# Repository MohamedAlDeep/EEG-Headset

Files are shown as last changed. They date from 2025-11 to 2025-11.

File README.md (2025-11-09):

# ADS1299 EEG Headset 🧠
This is a DIY / custom *electroencephalogram* reading device which is connected eeg electrodes that can connect to brain at designated areas.

It reads brain wave signals and digitizes them into the computer which is called brain-computer interface.

### Why am i doing this
I have a larger project and i want to join the competition with my pcb.

### The schematic 
This is the board schematic.
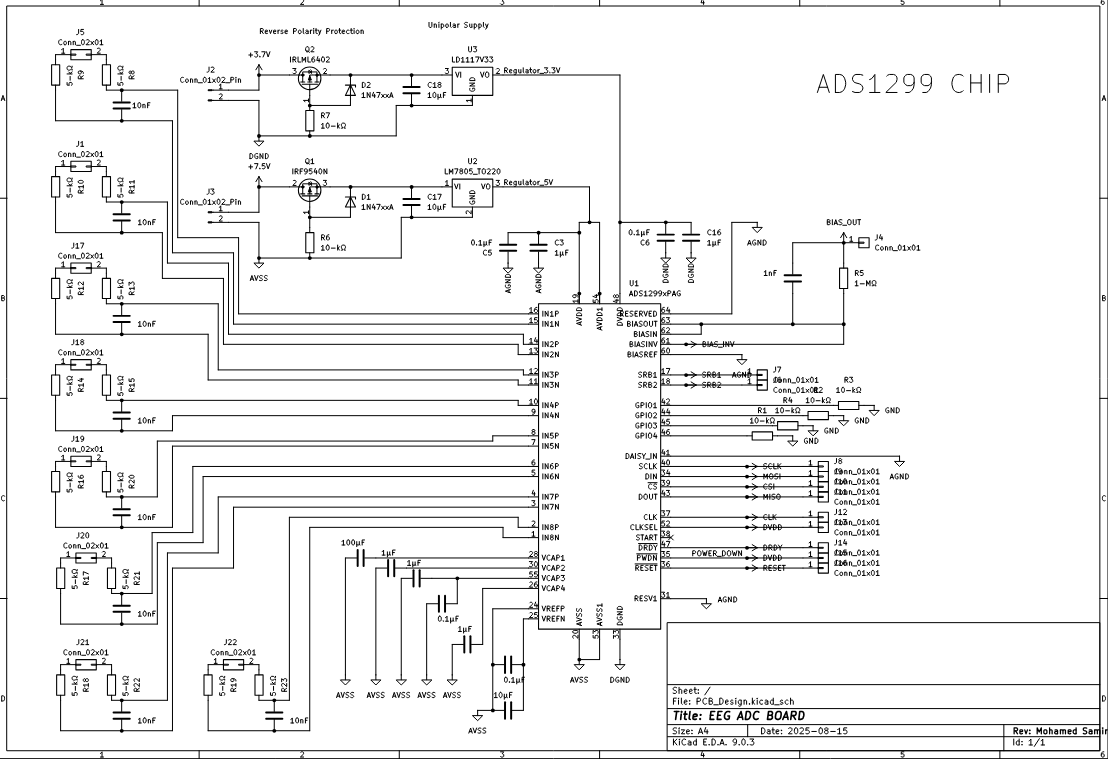
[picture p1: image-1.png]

### PCB
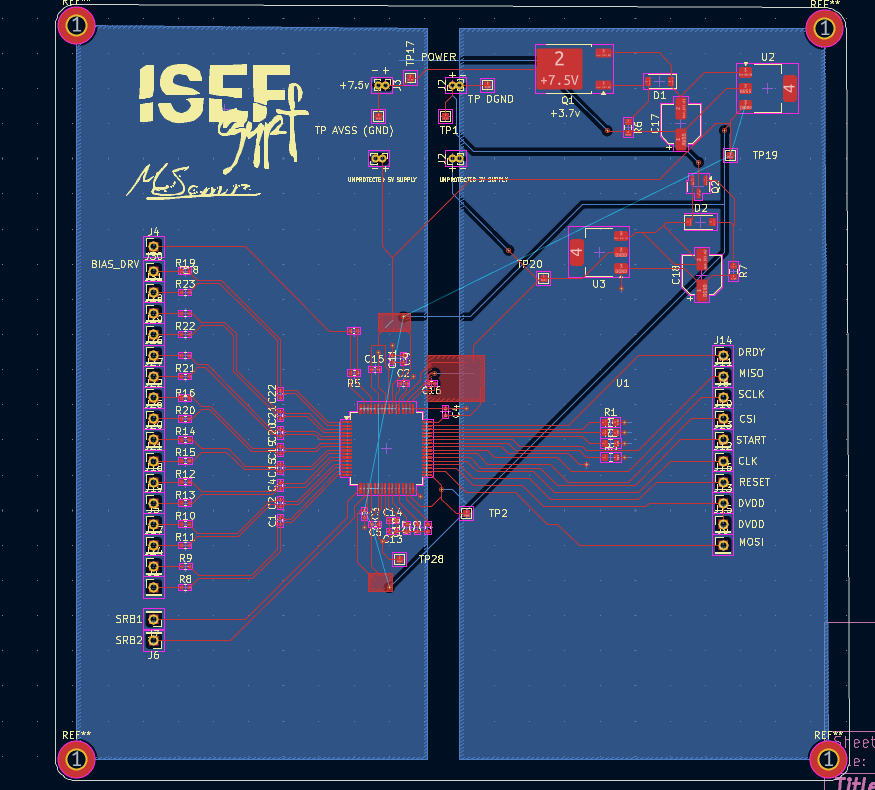
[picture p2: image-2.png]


### Mounting Part
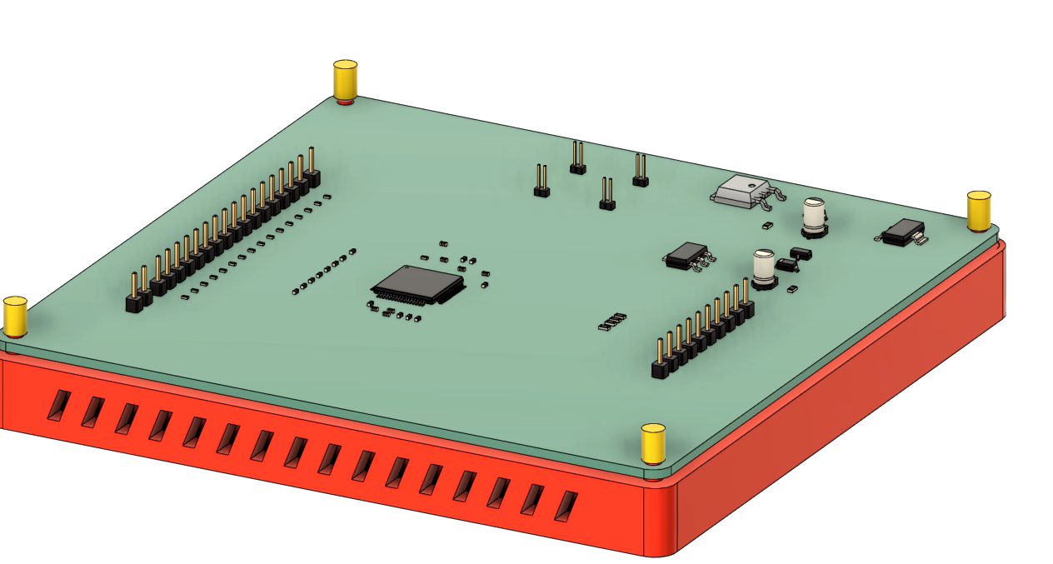
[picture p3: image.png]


### BOM 

| Item | Recommended_LCSC_PN | Package | JLCPCB_Type | URL | Unit Price | Amount | Total |
|:---|:---|:---|:---|:---|:---|:---|:---|
| EEG Electrodes | | | | https://ar.aliexpress.com/item/1005003431845612.html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 | 26.75 | 2.0 | 53.5 |
| 100nF (Original 6.3V) | C1525 | 402 | Basic | https://jlcpcb.com/partdetail/1877-CL05B104KO5NNNC/C1525 | $0.01 | 4.0 | 4 |
| 10nF | C1524 | 402 | Basic | https://jlcpcb.com/partdetail/1876-0402B103K500NT/C1524 | $0.01 | 9.0 | 0.09 |
| 1μF | C15684 | 402 | Basic | https://jlcpcb.com/partdetail/MurataElectronics-GRM155R60J105KE19D/C15684 | $0.01 | 7.0 | 0.07 |
| 10μF | C15849 | 402 | Basic | | $0.01 | 1.0 | 0.01 |
| 10μF (Electrolytic) | C86604 | CP_Elec_5x5.4  | Extended | https://jlcpcb.com/partdetail/HonorElec-RVT1E100M0505/C86604 | $0.03 | 2.0 | 0.06 |
| 10kΩ | C25804 | 603 | Basic | https://jlcpcb.com/partdetail/26547-0603WAF1002T5E/C25804 | 0.01 | 6.0 | 0.06 |
| 1MΩ | C26083 | 402 | Extended | https://jlcpcb.com/partdetail/26826-0402WGF1004TCE/C26083 | 0.01 | 1.0 | 0.01 |
| 5kΩ | C477765 | 402 | Extended | https://jlcpcb.com/partdetail/YAGEO-RC0402FR075KL/C477765 | $0.01 | 16.0 | 0.16 |
| 3.3V LDO | C5018 (AMS1117-3.3) | SOT-223 | Basic | https://jlcpcb.com/partdetail/Advanced_MonolithicSystems-AMS1117_33/C6186 | 0.16 | 1.0 | 0.16 |
| 5V LDO | C5019 (AMS1117-5.0) | SOT-223 | Basic | https://jlcpcb.com/partdetail/Advanced_MonolithicSystems-AMS1117_50/C6187 | 0.19 | 1.0 | 0.19 |
| P-MOSFET (SOT-23) | C10487 | SOT-23 | Basic | https://jlcpcb.com/partdetail/VishayIntertech-SI2301CDS_T1GE3/C10487 | 0.05 | 1.0 | 0.05 |
| FQD4P50 (P-MOSFET) | C17265 | SMD:SOT-223 | Extended | https://jlcpcb.com/partdetail/onsemi-NTF2955T1G/C17265 | 0.47 | 1.0 | 0.47 |
| Conn 1×01 Pin | C2938454 | SMT Pin Header | Basic | https://jlcpcb.com/partdetail/3294834-KH_2PH180_1X10P_L87/C2938454 | 0.05 | 2.0 | 0.1 |
| ADS1299IPAGR | C476817 | TQFP-64(10x10) | Economic and Standard | https://jlcpcb.com/partdetail/TexasInstruments-ADS1299IPAGR/C476817 | 30.66 | 1.0 | 30.66 |
| Total | | | | | | | 89.59 |

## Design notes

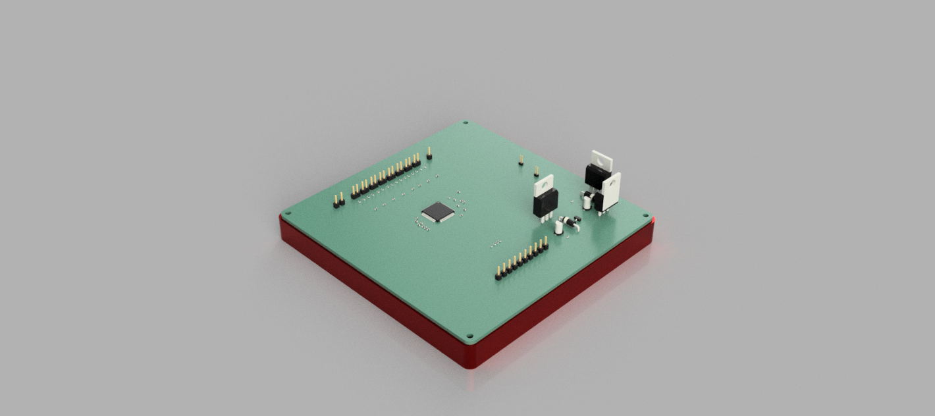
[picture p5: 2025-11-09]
Media/PCB_Holder v2.png

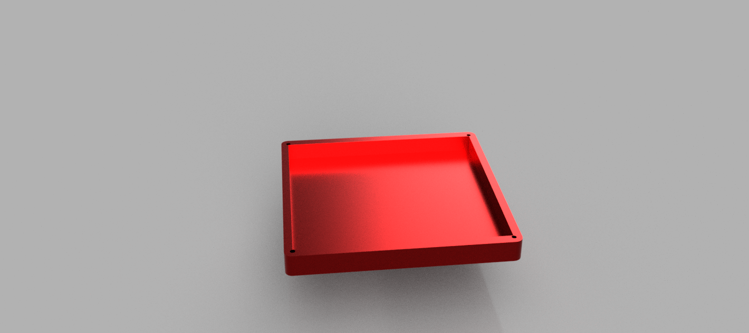
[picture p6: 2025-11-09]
Media/PCB_Holder v2 2.png

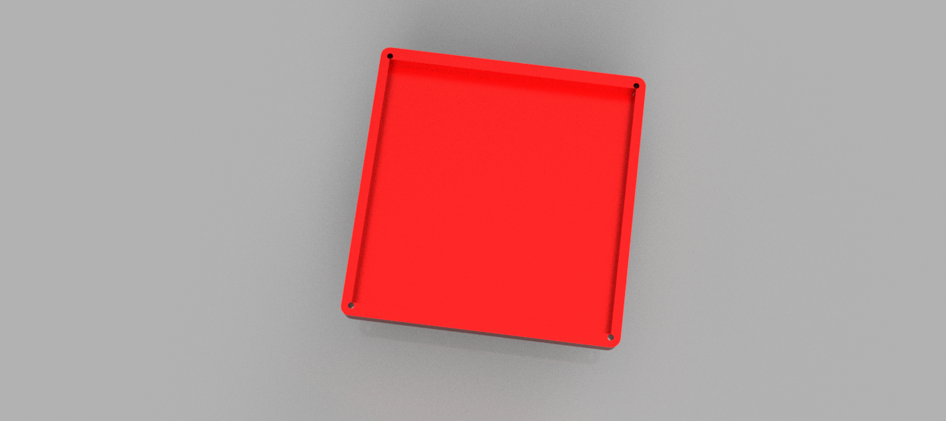
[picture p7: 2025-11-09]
Media/PCB_Holder v2 3.png

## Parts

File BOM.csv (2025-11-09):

Item | Recommended_LCSC_PN | Package | JLCPCB_Type | URL | Unit Price | Amount | Total
EEG Electrodes |  |  |  | https://ar.aliexpress.com/item/1005003431845612.html?curPageLogUid=TJmvYjdGyCeK | 26.75 | 2 | 53.5
100nF (Original 6.3V) | C1525 | 402 | Basic | https://jlcpcb.com/partdetail/1877-CL05B104KO5NNNC/C1525 | $0.01 | 4 | 4
10nF | C1524 | 402 | Basic | https://jlcpcb.com/partdetail/1876-0402B103K500NT/C1524 | $0.01 | 9 | 0.09
1μF | C15684 | 402 | Basic | https://jlcpcb.com/partdetail/MurataElectronics-GRM155R60J105KE19D/C15684 | $0.01 | 7 | 0.07
10μF | C15849 | 402 | Basic |  | $0.01 | 1 | 0.01
10μF (Electrolytic) | C86604 | CP_Elec_5x5.4 | Extended | https://jlcpcb.com/partdetail/HonorElec-RVT1E100M0505/C86604 | $0.03 | 2 | 0.06
10kΩ | C25804 | 603 | Basic | https://jlcpcb.com/partdetail/26547-0603WAF1002T5E/C25804 | 0.01 | 6 | 0.06
1MΩ | C26083 | 402 | Extended | https://jlcpcb.com/partdetail/26826-0402WGF1004TCE/C26083 | 0.01 | 1 | 0.01
5kΩ | C477765 | 402 | Extended | https://jlcpcb.com/partdetail/YAGEO-RC0402FR075KL/C477765 | $0.01 | 16 | 0.16
3.3V LDO | C5018 (AMS1117-3.3) | SOT-223 | Basic | https://jlcpcb.com/partdetail/Advanced_MonolithicSystems-AMS1117_33/C6186 | 0.16 | 1 | 0.16
5V LDO | C5019 (AMS1117-5.0) | SOT-223 | Basic | https://jlcpcb.com/partdetail/Advanced_MonolithicSystems-AMS1117_50/C6187 | 0.19 | 1 | 0.19
P-MOSFET (SOT-23) | C10487 | SOT-23 | Basic | https://jlcpcb.com/partdetail/VishayIntertech-SI2301CDS_T1GE3/C10487 | 0.05 | 1 | 0.05
FQD4P50 (P-MOSFET) | C17265 | SMD:SOT-223 | Extended | https://jlcpcb.com/partdetail/onsemi-NTF2955T1G/C17265 | 0.47 | 1 | 0.47
Conn 1×01 Pin | C2938454 | SMT Pin Header | Basic | https://jlcpcb.com/partdetail/3294834-KH_2PH180_1X10P_L87/C2938454 | 0.05 | 2 | 0.1
ADS1299IPAGR | C476817 | TQFP-64(10x10) | Economic and Standard | https://jlcpcb.com/partdetail/TexasInstruments-ADS1299IPAGR/C476817 | 30.66 | 1 | 30.66
Total |  |  |  |  |  |  | 89.59

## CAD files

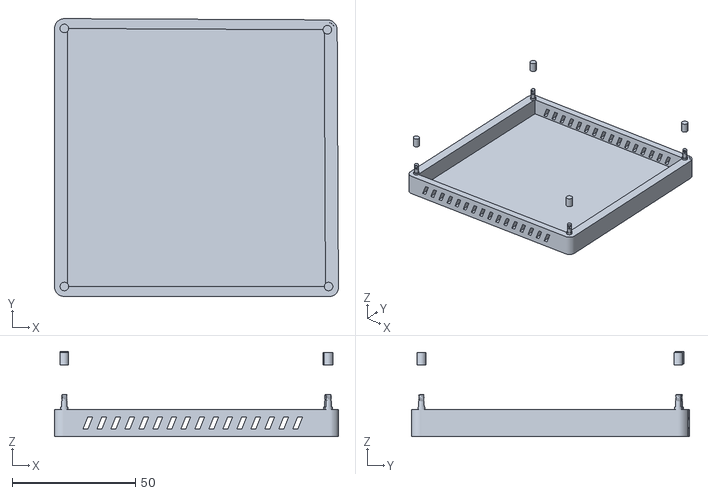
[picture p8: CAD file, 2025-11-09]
CAD/PCB_Holder_.stl
115.0 x 112.5 x 34.5

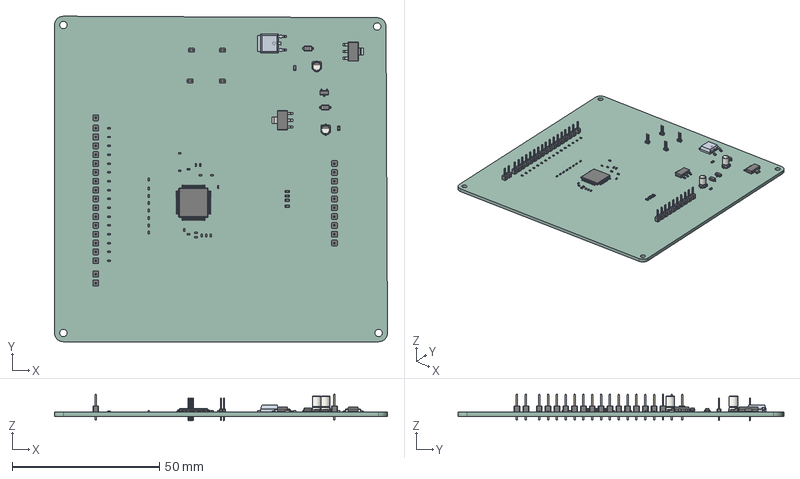
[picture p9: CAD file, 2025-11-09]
CAD/PCB_Design.step
113.0 x 110.5 x 9.00 mm
PinHeader_1x01_P2.00mm_Vertical x 29
R_0402_1005Metric x 17
C_0402_1005Metric x 22
SOT-23
R_0603_1608Metric x 6
D_SOD-123 x 2
PinHeader_1x02_P1.00mm_Vertical x 4
SOT-223 x 2
CP_Elec_3x5.4 x 2
TQFP-64_10x10mm_P0.5mm
PCB_Design 1.82.1
PCB_Design_PCB

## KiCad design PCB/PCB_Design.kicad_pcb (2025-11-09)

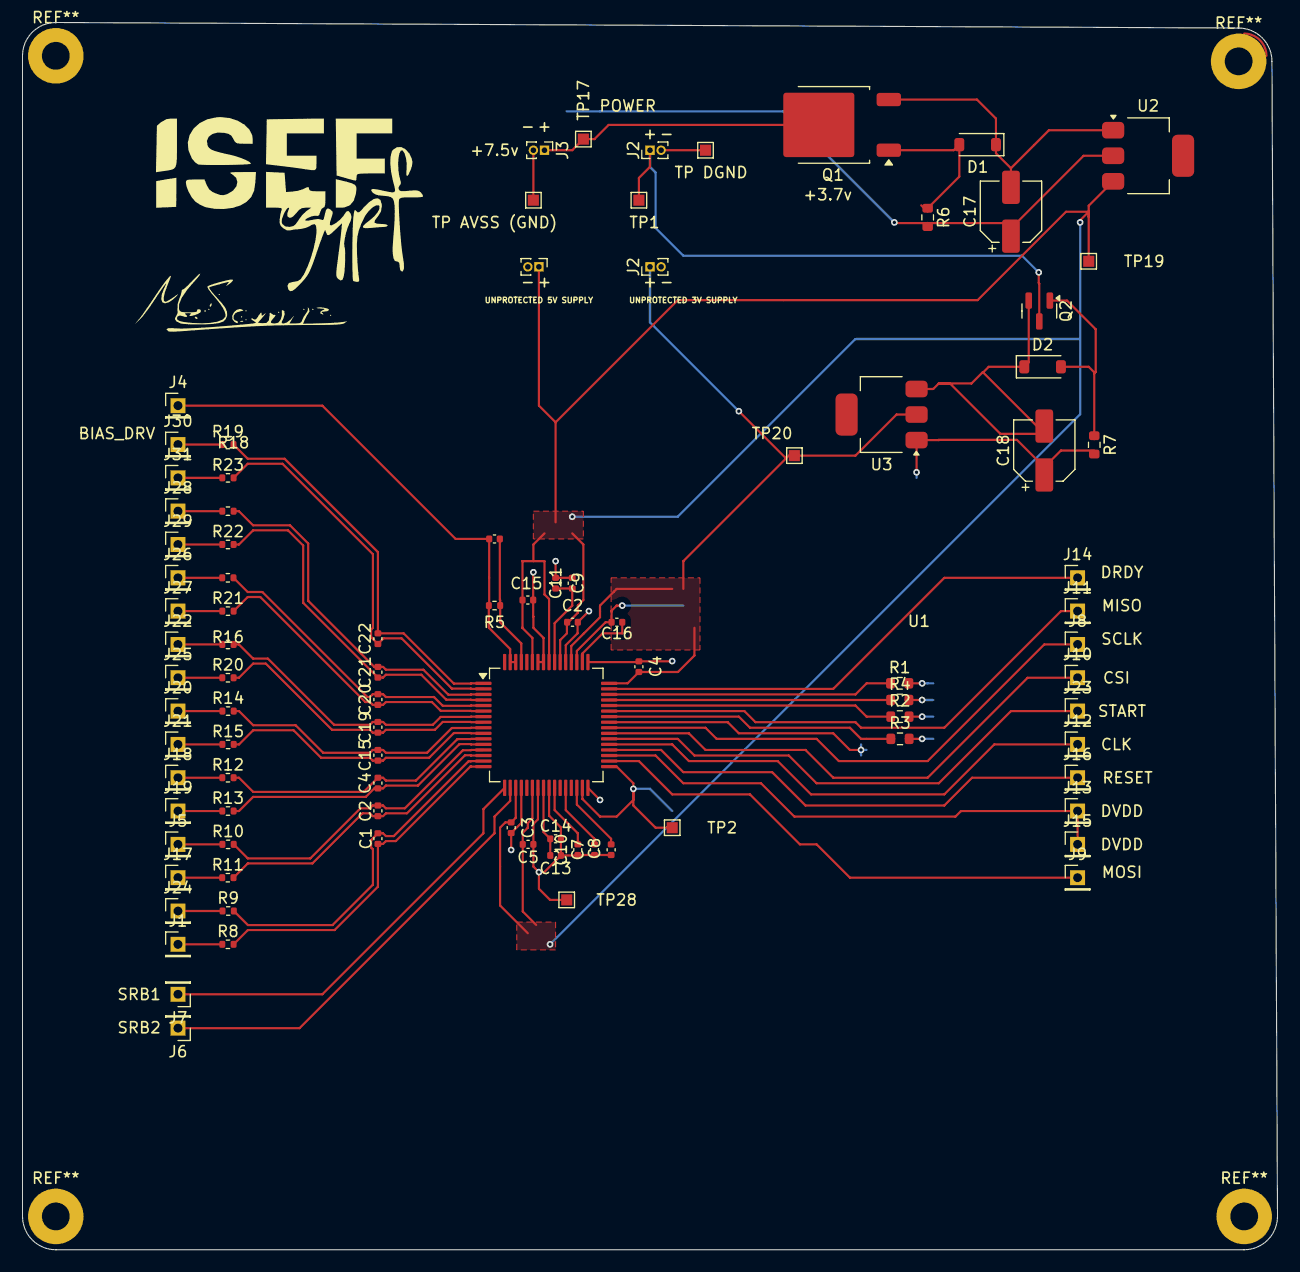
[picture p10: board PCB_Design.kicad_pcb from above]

Board: 2 copper layers, 113.0 x 110.5 mm, 95 parts (0 on the bottom side), 52 nets.

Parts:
C1, C2, C4, C12, C15#2, C19, C20, C21, C22: 10nF; C_0402_1005Metric
C2#2, C3, C8, C9, C10, C15, C16: 1μF; C_0402_1005Metric
C4#2: 100nF; C_0402_1005Metric
C5, C11, C13: 0.1μF; C_0402_1005Metric
C7: 100μF; C_0402_1005Metric
C14: 10μF; C_0402_1005Metric
C17, C18: 10μF; CP_Elec_5x5.4
D1: BZT52C5V1-W8 5.1V Zener 500mW; D_SOD-123
D2: 1N47xxA; D_SOD-123
J1, J4, J5, J6, J7, J8, J9, J10, J11, J12, J13, J14, J15, J16, J17, J18, J19, J20, J21, J22, J23, J24, J25, J26, J27, J28, J29, J30, J31: Conn_01x01; PinHeader_1x01_P2.00mm_Vertical
J2, J2#2, J3: Conn_01x02_Pin; PinHeader_1x02_P1.00mm_Vertical
Q1: FQD4P50 (P-MOSFET); TO-252-2
Q2: IRLML6402; SOT-23
R1, R2, R3, R4, R6, R7: 10-kΩ; R_0603_1608Metric
R5: 1-MΩ; R_0402_1005Metric
R8, R9, R10, R11, R12, R13, R14, R15, R16, R17, R18, R19, R20, R21, R22, R23: 5-kΩ; R_0402_1005Metric
TP1, TP2, TP17, TP19, TP20, TP28: TestPoint; TestPoint_Pad_1.0x1.0mm
TP AVSS (GND): TestPoint; TestPoint_Pad_1.0x1.0mm
TP DGND: TestPoint; TestPoint_Pad_1.0x1.0mm
U1: ADS1299xPAG; TQFP-64_10x10mm_P0.5mm
U2: LM7805_TO220; SOT-223
U3: AMS1117-3.3; SOT-223
UNPROTECTED 5V SUPPLY: Conn_01x02_Pin; PinHeader_1x02_P1.00mm_Vertical

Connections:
+3.7V: J2#2.1, Q2.3 (D), TP1.1
+7.5V: J3.1, Q1.2 (D), TP17.1
/AVDD: C3.1, C5.2, TP19.1, U2.3 (VO)
/IN+: C1.2, C2.1, C4.1, C15#2.1, C19.1, C20.1, C21.1, C22.1, R8.2, R11.2, R13.2, R15.2, R20.2, R21.2, R22.2, R23.2, U1.2 (IN8P), U1.4 (IN7P), U1.6 (IN6P), U1.8 (IN5P), U1.10 (IN4P), U1.12 (IN3P), U1.14 (IN2P), U1.16 (IN1P)
/IN-: C1.1, C2.2, C4.2, C15#2.2, C19.2, C20.2, C21.2, C22.2, R9.2, R10.2, R12.2, R14.2, R16.2, R17.2, R18.2, R19.2, U1.1 (IN8N), U1.3 (IN7N), U1.5 (IN6N), U1.7 (IN5N), U1.9 (IN4N), U1.11 (IN3N), U1.13 (IN2N), U1.15 (IN1N)
AGND: U1.60 (BIASREF), U1.64 (RESERVED)
AVDD: C2#2.1, C15.1, UNPROTECTED 5V SUPPLY.1
AVSS: C2#2.2, C3.2, C5.1, C7.1, C8.1, C9.1, C10.1, C11.2, C13.1, C14.2, C15.2, C17.1, J3.2, R6.2, TP28.1, TP AVSS (GND).1, U1.20 (AVSS), U1.23 (AVSS), U1.25 (VREFN), U1.32 (AVSS), U1.53 (AVSS1), U1.57 (AVSS), U1.58 (AVSS), U2.2 (GND), UNPROTECTED 5V SUPPLY.2
BIAS_INV: C12.1, R5.1, U1.61 (BIASINV)
BIAS_OUT: C12.2, J4.1, R5.2, U1.62 (BIASIN), U1.63 (BIASOUT)
CLK: J12.1, U1.37 (CLK)
CSI: J10.1, U1.39 (~CS)
DGND: C4#2.1, C16.2, C18.1, J2.2, J2#2.2, R1.2, R2.2, R3.2, R4.2, R7.2, TP2.1, TP DGND.1, U1.31 (RESV1), U1.33 (DGND), U1.41 (DAISY_IN), U1.49 (DGND), U1.51 (DGND), U3.1 (GND)
DRDY: J14.1, U1.47 (~DRDY)
DVDD: C4#2.2, C16.1, J2.1, J13.1, J15.1, TP20.1, U1.35 (~PWDN), U1.48 (DVDD), U1.50 (DVDD), U1.52 (CLKSEL), U3.2 (VO)
MISO: J11.1, U1.43 (DOUT)
MOSI: J9.1, U1.34 (DIN)
unnamed: D1.2 (A), Q1.1 (G), R6.1
unnamed: C17.2, D1.1 (K), Q1.3 (S), U2.1 (VI)
unnamed: D2.2 (A), Q2.1 (G), R7.1
unnamed: C18.2, D2.1 (K), Q2.2 (S), U3.3 (VI)
unnamed: J1.1, R8.1
unnamed: J5.1, R10.1
unnamed: J17.1, R11.1
unnamed: J18.1, R12.1
unnamed: J19.1, R13.1
unnamed: J20.1, R14.1
unnamed: J21.1, R15.1
unnamed: J22.1, R16.1
unnamed: J24.1, R9.1
unnamed: J25.1, R20.1
unnamed: J26.1, R17.1
unnamed: J27.1, R21.1
unnamed: J28.1, R18.1
unnamed: J29.1, R22.1
unnamed: J30.1, R19.1
unnamed: J31.1, R23.1
unnamed: U1.19 (AVDD), U1.21 (AVDD), U1.22 (AVDD), U1.56 (AVDD), U1.59 (AVDD)
unnamed: R3.1, U1.42 (GPIO1)
unnamed: R2.1, U1.44 (GPIO2)
unnamed: R4.1, U1.45 (GPIO3)
unnamed: R1.1, U1.46 (GPIO4)
unnamed: C7.2, U1.28 (VCAP1)
unnamed: C8.2, U1.30 (VCAP2)
unnamed: C9.2, C11.1, U1.55 (VCAP3)
unnamed: C10.2, U1.26 (VCAP4)
unnamed: C13.2, C14.1, U1.24 (VREFP)
RESET: J16.1, U1.36 (~RESET)
SCLK: J8.1, U1.40 (SCLK)
SRB1: J7.1, U1.17 (SRB1)
SRB2: J6.1, U1.18 (SRB2)
START: J23.1, U1.38 (START)
